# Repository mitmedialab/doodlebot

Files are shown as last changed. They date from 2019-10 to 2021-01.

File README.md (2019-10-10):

# The Minimal theme

 

*Minimal is a Jekyll theme for GitHub Pages. You can [preview the theme to see what it looks like](http://pages-themes.github.io/minimal), or even [use it today](#usage).*

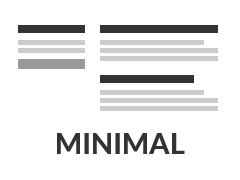
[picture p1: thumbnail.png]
Thumbnail of minimal


## Usage

To use the Minimal theme:

1. Add the following to your site's `_config.yml`:

    ```yml
    theme: jekyll-theme-minimal
    ```

2. Optionally, if you'd like to preview your site on your computer, add the following to your site's `Gemfile`:

    ```ruby
    gem "github-pages", group: :jekyll_plugins
    ```

## Customizing

### Configuration variables

Minimal will respect the following variables, if set in your site's `_config.yml`:

```yml
title: [The title of your site]
description: [A short description of your site's purpose]
```

Additionally, you may choose to set the following optional variables:

```yml
logo: [Location of the logo]
show_downloads: ["true" or "false" to indicate whether to provide a download URL]
google_analytics: [Your Google Analytics tracking ID]
```

### Stylesheet

If you'd like to add your own custom styles:

1. Create a file called `/assets/css/style.scss` in your site
2. Add the following content to the top of the file, exactly as shown:
    ```scss
    ---
    ---

    @import "{{ site.theme }}";
    ```
3. Add any custom CSS (or Sass, including imports) you'd like immediately after the `@import` line

### Layouts

If you'd like to change the theme's HTML layout:

1. [Copy the original template](https://github.com/pages-themes/minimal/blob/master/_layouts/default.html) from the theme's repository<br />(*Pro-tip: click "raw" to make copying easier*)
2. Create a file called `/_layouts/default.html` in your site
3. Paste the default layout content copied in the first step
4. Customize the layout as you'd like

## Roadmap

See the [open issues](https://github.com/pages-themes/minimal/issues) for a list of proposed features (and known issues).

## Project philosophy

The Minimal theme is intended to make it quick and easy for GitHub Pages users to create their first (or 100th) website. The theme should meet the vast majority of users' needs out of the box, erring on the side of simplicity rather than flexibility, and provide users the opportunity to opt-in to additional complexity if they have specific needs or wish to further customize their experience (such as adding custom CSS or modifying the default layout). It should also look great, but that goes without saying.

## Contributing

Interested in contributing to Minimal? We'd love your help. Minimal is an open source project, built one contribution at a time by users like you. See [the CONTRIBUTING file](docs/CONTRIBUTING.md) for instructions on how to contribute.

### Previewing the theme locally

If you'd like to preview the theme locally (for example, in the process of proposing a change):

1. Clone down the theme's repository (`git clone https://github.com/pages-themes/minimal`)
2. `cd` into the theme's directory
3. Run `script/bootstrap` to install the necessary dependencies
4. Run `bundle exec jekyll serve` to start the preview server
5. Visit [`localhost:4000`](http://localhost:4000) in your browser to preview the theme

### Running tests

The theme contains a minimal test suite, to ensure a site with the theme would build successfully. To run the tests, simply run `script/cibuild`. You'll need to run `script/bootstrap` one before the test script will work.

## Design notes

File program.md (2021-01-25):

## Program Your DoodleBot!

Connect the Doodle Bot to the computer using a USB cord. 

Download Arduino IDE from [https://www.arduino.cc/en/main/software](https://www.arduino.cc/en/main/software)  or use the online Arduino tool at [https://create.arduino.cc](https://create.arduino.cc) 

First upload the following code to the Doodle bot to check for calibration of the bot. This programs the robot to draw 4 rectangles on top of each other. If your robot does not draw the rectangles on top of each other, then the wheels are not calibrated accurately. 

Note that you need to select your Arduino type in **Tools > Board > Arduino Nano** (or whichever Arduino you are using) 

Note that you must also select the appropriate port in **Tools > Port > USB-XX** (port name shows up when you connect your bot to the computer using USB)

```
#include <Servo.h>

// setup servo
int servoPin = 8;
int PEN_DOWN = 20; // angle of servo when pen is down
int PEN_UP = 80;   // angle of servo when pen is up
Servo penServo;

float wheel_dia=63; //    # mm (increase = spiral out)
float wheel_base=109; //    # mm (increase = spiral in, ccw) 
int steps_rev=128; //        # 512 for 64x gearbox, 128 for 16x gearbox
int delay_time=6; //         # time between steps in ms

// Stepper sequence org->pink->blue->yel
int L_stepper_pins[] = {12, 10, 9, 11};
int R_stepper_pins[] = {4, 6, 7, 5};

int fwd_mask[][4] =  {1, 0, 1, 0}, {0, 1, 1, 0}, {0, 1, 0, 1}, {1, 0, 0, 1};

int rev_mask[][4] =  {1, 0, 0, 1},{0, 1, 0, 1},{0, 1, 1, 0},{1, 0, 1, 0};

void setup() {
  randomSeed(analogRead(1)); 
  Serial.begin(9600);
  for(int pin=0; pin<4; pin++){
    pinMode(L_stepper_pins[pin], OUTPUT);
    digitalWrite(L_stepper_pins[pin], LOW);
    pinMode(R_stepper_pins[pin], OUTPUT);
    digitalWrite(R_stepper_pins[pin], LOW);
  }
  penServo.attach(servoPin);
  Serial.println("setup");
  
  penup();
  
  delay(1000);
}

void loop(){ // draw a calibration box 4 times
  pendown();
  for(int x=0; x<12; x++){
    forward(100);
    left(90);
  }
  penup();
  done();      // releases stepper motor
  while(1);    // wait for reset
}

// ----- HELPER FUNCTIONS -----------
int step(float distance){
  int steps = distance * steps_rev / (wheel_dia * 3.1412); //24.61
  /*
  Serial.print(distance);
  Serial.print(" ");
  Serial.print(steps_rev);
  Serial.print(" ");  
  Serial.print(wheel_dia);
  Serial.print(" ");  
  Serial.println(steps);
  delay(1000);*/
  return steps;  
}

void forward(float distance){
  int steps = step(distance);
  Serial.println(steps);
  for(int step=0; step<steps; step++){
    for(int mask=0; mask<4; mask++){
      for(int pin=0; pin<4; pin++){
        digitalWrite(L_stepper_pins[pin], rev_mask[mask][pin]);
        digitalWrite(R_stepper_pins[pin], fwd_mask[mask][pin]);
      }
      delay(delay_time);
    } 
  }
}

void backward(float distance){
  int steps = step(distance);
  for(int step=0; step<steps; step++){
    for(int mask=0; mask<4; mask++){
      for(int pin=0; pin<4; pin++){
        digitalWrite(L_stepper_pins[pin], fwd_mask[mask][pin]);
        digitalWrite(R_stepper_pins[pin], rev_mask[mask][pin]);
      }
      delay(delay_time);
    } 
  }
}

void right(float degrees){
  float rotation = degrees / 360.0;
  float distance = wheel_base * 3.1412 * rotation;
  int steps = step(distance);
  for(int step=0; step<steps; step++){
    for(int mask=0; mask<4; mask++){
      for(int pin=0; pin<4; pin++){
        digitalWrite(R_stepper_pins[pin], rev_mask[mask][pin]);
        digitalWrite(L_stepper_pins[pin], rev_mask[mask][pin]);
      }
      delay(delay_time);
    } 
  }   
}

void left(float degrees){
  float rotation = degrees / 360.0;
  float distance = wheel_base * 3.1412 * rotation;
  int steps = step(distance);
  for(int step=0; step<steps; step++){
    for(int mask=0; mask<4; mask++){
      for(int pin=0; pin<4; pin++){
        digitalWrite(R_stepper_pins[pin], fwd_mask[mask][pin]);
        digitalWrite(L_stepper_pins[pin], fwd_mask[mask][pin]);
      }
      delay(delay_time);
    } 
  }   
}

void done(){ // unlock stepper to save battery
  for(int mask=0; mask<4; mask++){
    for(int pin=0; pin<4; pin++){
      digitalWrite(R_stepper_pins[pin], LOW);
      digitalWrite(L_stepper_pins[pin], LOW);
    }
    delay(delay_time);
  }
}

void penup(){
  delay(250);
  Serial.println("PEN_UP()");
  penServo.write(PEN_UP);
  delay(250);
}

void pendown(){
  delay(250);  
  Serial.println("PEN_DOWN()");
  penServo.write(PEN_DOWN);
  delay(250);
}

```

Calibration functions 

```
void loop(){ // draw a calibration box 4 times
  pendown();
  for(int x=0; x<12; x++){
    forward(100);
    left(90);
  }
  penup();
  done();      // releases stepper motor
  while(1);    // wait for reset
}
```

```
void loop(){ // draw a calibration Octagon 2 times
  pendown();
  for(int x=0; x<16; x++){
    forward(100);
    left(45);
  }
  penup();
  done();      // releases stepper motor
  while(1);    // wait for reset
}
```

```
void loop(){ // draw 2 concentric circles - try out resolutions
  pendown();
  for(int x=0; x<180; x++){
    forward(2);
    left(2);
  }
  penup();

  right(90);
  forward(100);
  left(90);

  pendown();
  for(int x=0; x<180; x++){
    forward(2);
    left(2);
  }
  penup();

  done();      // releases stepper motor
  while(1);    // wait for reset
}
```

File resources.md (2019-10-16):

# Resources

**STL and CAD files for 3D printing**: https://github.com/mitmedialab/doodlebot/blob/master/parts

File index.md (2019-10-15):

---
layout: default
---

Doodle Bot is a robot-based Creative AI learning platform for High School students. It consists of an introduction to robotics, hardware, arduino programming and machine learning.

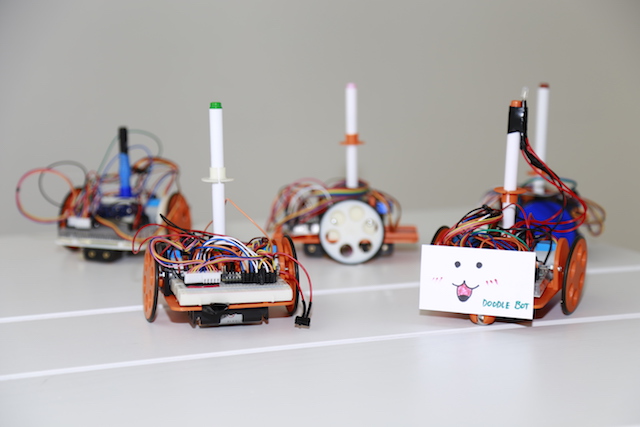
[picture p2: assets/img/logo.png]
MainImage


Doodle Bot has three main modules : 

* **Construction** : Students learn how to print and construct the robot. Students learn physical fabrication, hardware skills, electronics and circuit design. 
* **Programming** : Students learn how to program the robot to draw different shapes. Students gain Arduino programming skills. Students also learn converting stroke paths to Arduino paths.
* **Training** : Students learn the basics of Machine Learning (Classification, Generative Networks). Students train their robot in ways specific to their project. 

In addition, you can also refer to our [projects gallery](./projects.html) for previous projects, and [resources](./resources.html) to download model files and source code.  

This project is developed and maintained by MIT. Note that the Doodle robot and its training module has been used for robotics and STEM workshop for over 30 high school students in the US and Mexico. 

For any questions and suggestions, please contact : 

* Safinah Ali : safinah@mit.edu
* Nisha Devasia : ndevasia@mit.edu

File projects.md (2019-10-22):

# Projects

Here are some DoodleBot projects that were created this summer!

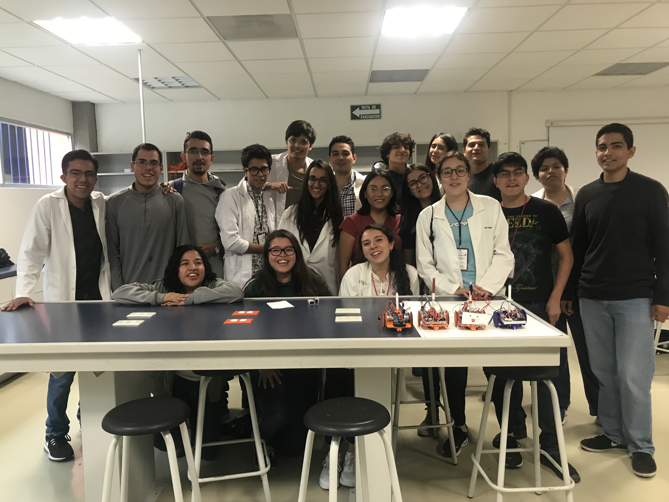
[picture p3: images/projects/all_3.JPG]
The entire team!

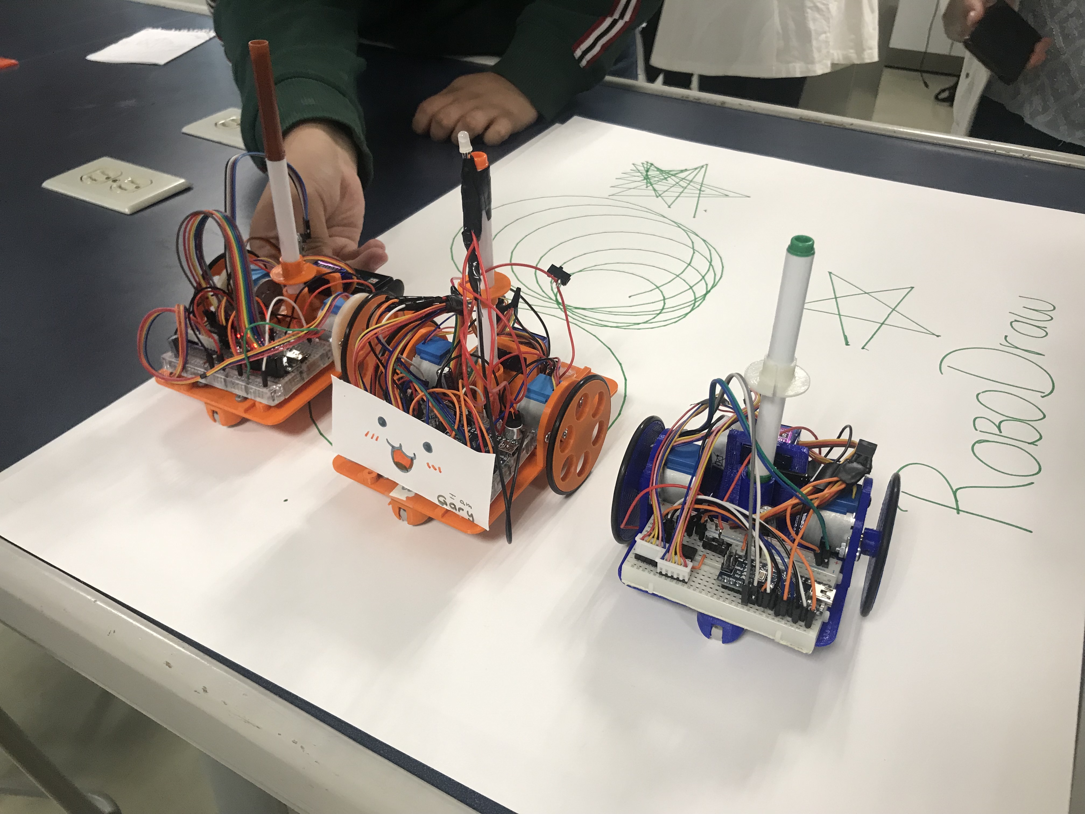
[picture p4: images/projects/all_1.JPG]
The doodlebots

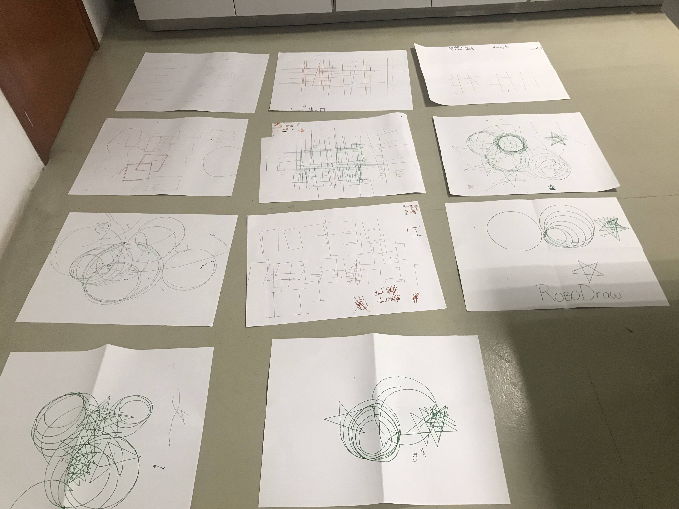
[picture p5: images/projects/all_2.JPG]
Doodlebot drawings


## Team 1

Here is an individual project, [project name], created by [team members]. 

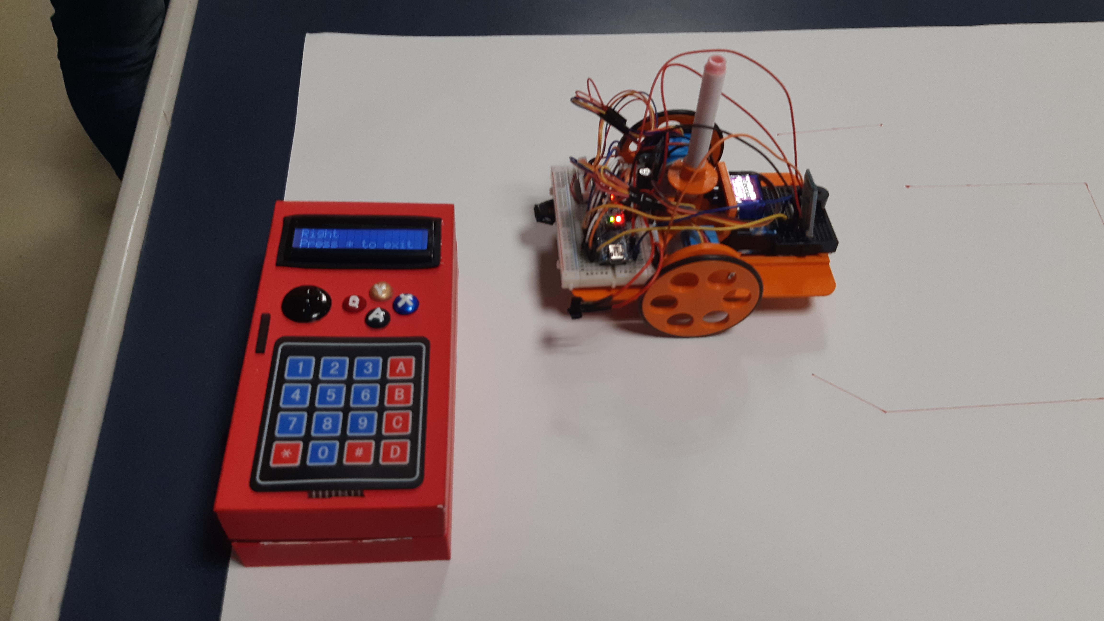
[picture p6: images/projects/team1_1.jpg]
project

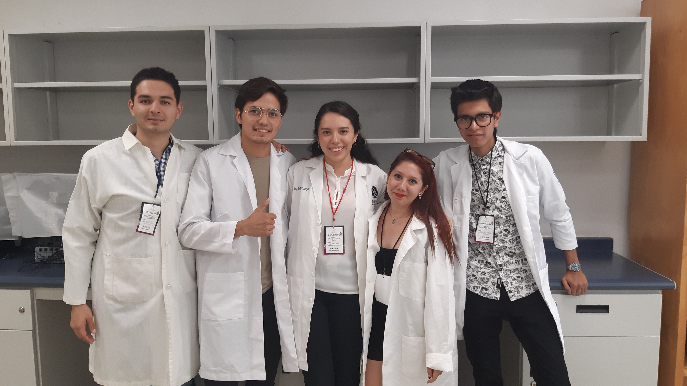
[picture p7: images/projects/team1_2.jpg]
project


## Team 2

Here is an individual project, [project name], created by [team members]. 

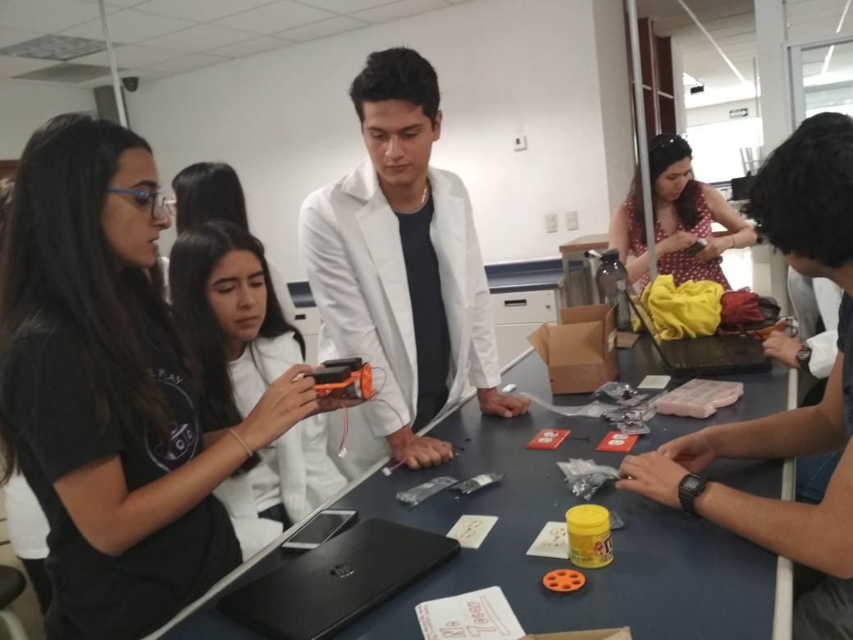
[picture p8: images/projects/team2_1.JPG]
project


## Team 3

Here is an individual project, [project name], created by [team members]. 

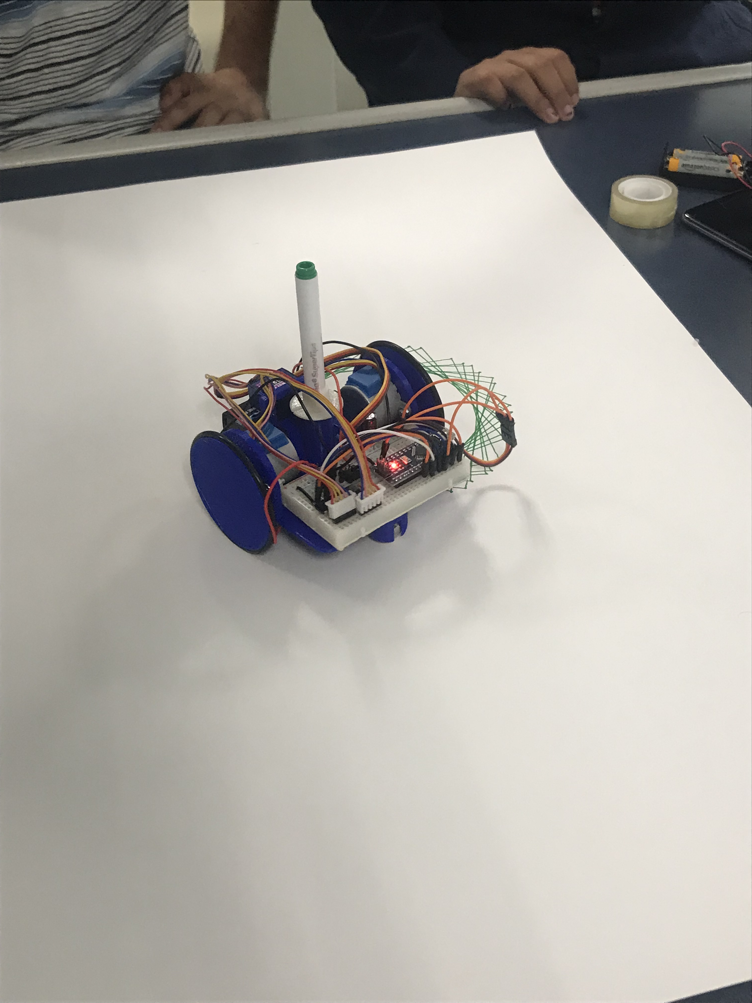
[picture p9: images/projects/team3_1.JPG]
project


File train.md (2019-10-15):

# Train Your DoodleBot!

## Sound classification

**Main steps:**

1. Set up a server with the boilerplace that uses ML5
2. Use a pre-trained model speech-commands to recognize speech
3. Design a web interface that recognized the speech word and prints it to a file
4. Use this file to load the current speech and send it to Arduino 

**Step 1: Set up a server with the boilerplate that uses ML5**

1. Download the boilerplate here : https://drive.google.com/open?id=14w6u65YhrZ5H0LI_JHK-Zqxa3Mltz3X1
2. In the folder above, you will find two files : index.html and sketch.js. Your HTML code (interface) will go in index.html file, and your Javascript code will go in the sketch.js file. 
3. Let’s examine the files : 
  a. index.html 

  Verify that your code in **index.html** looks like this: 

  This code contains html tags <head> and <body>. In the ```<head>```, we load all the p5.js libraries which are responsible for the look and feel of the webpage and in the ```<body>```, we load the sketch.js file, while is responsible for the logic of the webpage. 

```html
<!DOCTYPE html>
<html lang="en">
  <head>
    <title>Getting Started with ml5.js</title>
    <!-- p5 -->
    <script src="https://cdnjs.cloudflare.com/ajax/libs/p5.js/0.8.0/p5.min.js"></script>
    <script src="https://cdnjs.cloudflare.com/ajax/libs/p5.js/0.8.0/addons/p5.dom.min.js"></script>
    <script src="https://cdnjs.cloudflare.com/ajax/libs/p5.js/0.8.0/addons/p5.sound.min.js"></script>
    <!-- ml5 -->
    <script src="https://unpkg.com/ml5@0.3.0/dist/ml5.min.js"></script>
  </head>

  <body>
    <script src="sketch.js"></script>
  </body>
</html>
```

  b. sketch.js

This is the base sketch file. All p5.js files have a setup() function, where you set up your space, and a draw() which updates constantly to run stuff. To learn more, go to: https://p5js.org

```javascript
console.log('ml5 version:', ml5.version);

function setup(){
    createCanvas(400, 400);
}

function draw(){
    background(200);
    
}
```

In this **sketch.js** file, we simply make a canvas and we print the ml5 version to our console in the browser. We will first test if this works.
	
  c. Run the server. 

In order to test if this is working, we will run a local server. 

Go to your terminal, and navigate to the directory: 

  * First navigate to home directory in the terminal: 
  ```cd```
  * Then navigate to the project directory (this will depend on where your boilerplate folder is):
  ```cd Documents/biolerplate-sound```

Your folder might be in downloads instead of documents for example, if this is the case, replace the ```cd Documents/``` part with ```cd Downloads/```.

  * In this folder, run the following command in your terminal to start a local server : 
  ```python -m SimpleHTTPServer 8000```

  * If you get an error here, check what python version you have by using which python in your terminal. It should give you a result like : ```/Library/Frameworks/Python.framework/Versions/2.7/bin/python```.

  * This also works:
  ```(//anaconda3/bin/python)```
  If this is the case put this in instead:
   ```python3 -m http.server```

  * If it leads to no result, it means you need to install python. 

  * In order to test if the server is running, go to: http://localhost:8000 in your browser and you should see this: 

If you right click and go to ```inspect element >``` and then select the ‘console’ tab, you can see the browser’s console. In the console, you should see: ```0.3.0``` to verify that your server is working correctly. 

Now stop your server in the terminal. If you Control+C in your terminal, the server should stop. 

## Step 2: Use a pre-trained model SoundClassifier to recognize speech words : 

The model we will be using is called speech-commands recognizer model. The ml5.soundClassifier() allows you to classify audio. With the right pre-trained models, you can detect whether a certain noise was made (e.g. a clapping sound or a whistle) or a certain word was said (e.g. Up, Down, Yes, No). At this moment, with the ml5.soundClassifier(), you can use the "SpeechCommands18w" which can recognize "the ten digits from "zero" to "nine", "up", "down", "left", "right", "go", "stop", "yes", "no", as well as the additional categories of "unknown word" and "background noise"."

To read more about this mode, go to : https://github.com/tensorflow/tfjs-models/tree/master/speech-commands

For our application, we will use numbers, directions, “go”, and “stop” to make the doodle bot draw things. Ensure that your Arduino file has functions for all of these (zero" to "nine", "up", "down", "left", "right", "go", "stop")

  1. Open the index.html file. In the <head> tag, let’s first make the title of the page relevant to sound classification. 

  ```html
  <title>Sound classification using SpeechCommands18w and p5.js</title>
```

  In the body tag, we will write some info to display what the model is actually doing.
  
```html
<body>
  <h1>Sound classification using SpeechCommands18w and p5.js</h1>
  <p>Try to speak the following commands to your microphone: 'zero', 'one', 'two', 'three', 'four', 'five', 'six', 'seven', 'eight', 'nine', 'up', 'down', 'left', 'right', 'go', 'stop', 'yes', and 'no', in addition to 'background_noise' and 'unknown'</p>
  <script src="sketch.js"></script>
</body>
```

  2. Open the **sketch.js** file. Let’s first get rid of the createCanvas from the biolerplate, since we don’t need that. In addition to the setup() and sketch() function, we will add a preload() function before setup(). The preload() function loads the model in advance, in effect saving us time to load the model (when it is added in setup()), even before the interface is loaded. We do this since it quickens the process of loading the model, which is typically time consuming.

```javascript
function preload() {
  // Load SpeechCommands18w sound classifier model
  classifier = ml5.soundClassifier('SpeechCommands18w', options);
}
```

  3. We will now declare some variables in the beginning of **sketch.js**.

```javascript
// Initialize a sound classifier method with SpeechCommands18w model.
let classifier;
// Options for the SpeechCommands18w model, the default probabilityThreshold is 0
const options = { probabilityThreshold: 0.7 };
// Two variable to hold the label and confidence of the result
let label;
let confidence;
```

  4. setup() function:

```javascript
function setup() {
  noCanvas();
  // Create 'label' and 'confidence' div to hold results
  label = createDiv('Label: ...');
  confidence = createDiv('Confidence: ...');
  // Classify the sound from microphone in real time
  classifier.classify(gotResult);
}

  5. gotResult() function:
```javascript
// A function to run when we get any errors and the results
function gotResult(error, results) {
  // Display error in the console
  if (error) {
    console.error(error);
  }
  // The results are in an array ordered by confidence.
  console.log(results);
  // Show the first label and confidence
  label.html('Label: ' + results[0].label);
  confidence.html('Confidence: ' + nf(results[0].confidence, 0, 2)); // Round the confidence to 0.01
}
```

  6. Finally, your **sketch.js** file should look this this: 

```javascript
// Initialize a sound classifier method with SpeechCommands18w model. A callback needs to be passed.
let classifier;
// Options for the SpeechCommands18w model, the default probabilityThreshold is 0
const options = { probabilityThreshold: 0.7 };
// Two variable to hold the label and confidence of the result
let label;
let confidence;

function preload() {
  // Load SpeechCommands18w sound classifier model
  classifier = ml5.soundClassifier('SpeechCommands18w', options);
}

function setup() {
  noCanvas();
  // Create 'label' and 'confidence' div to hold results
  label = createDiv('Label: ...');
  confidence = createDiv('Confidence: ...');
  // Classify the sound from microphone in real time
  classifier.classify(gotResult);
}

// A function to run when we get any errors and the results
function gotResult(error, results) {
  // Display error in the console
  if (error) {
    console.error(error);
  }
  // The results are in an array ordered by confidence.
  console.log(results);
  // Show the first label and confidence
  label.html('Label: ' + results[0].label);
  confidence.html('Confidence: ' + nf(results[0].confidence, 0, 2)); // Round the confidence to 0.01
}
```

Now run your server again (Step 3.c.) and load the localhost in your browser. 

  7. Now write the result to a file in your arduino folder by using the write(data) function of p5.js. Read that file using Arduino IDE to tell the robot what to draw. 

  For reference: 
  * P5.js side (in your sketch.js file) : https://p5js.org/reference/#/p5.PrintWriter/write
  * Arduino side (in your .ino file) https://www.arduino.cc/en/Reference/FileRead

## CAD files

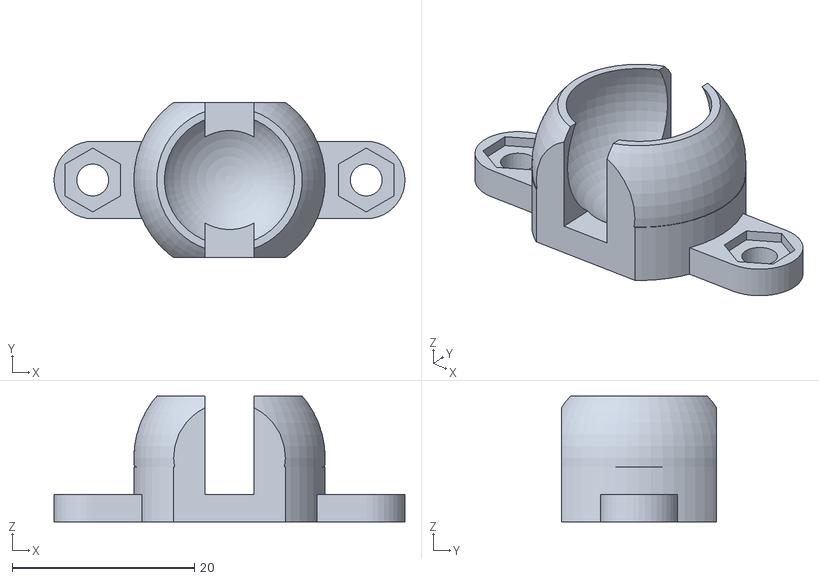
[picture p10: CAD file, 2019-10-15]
parts/STL files/Caster2.stl
38.5 x 17.0 x 13.8

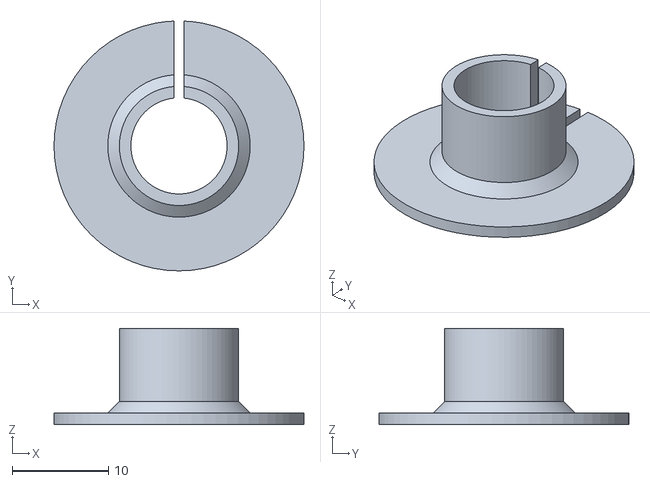
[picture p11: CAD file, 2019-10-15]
parts/STL files/Pen_Collar2.stl
26.0 x 26.0 x 10.0

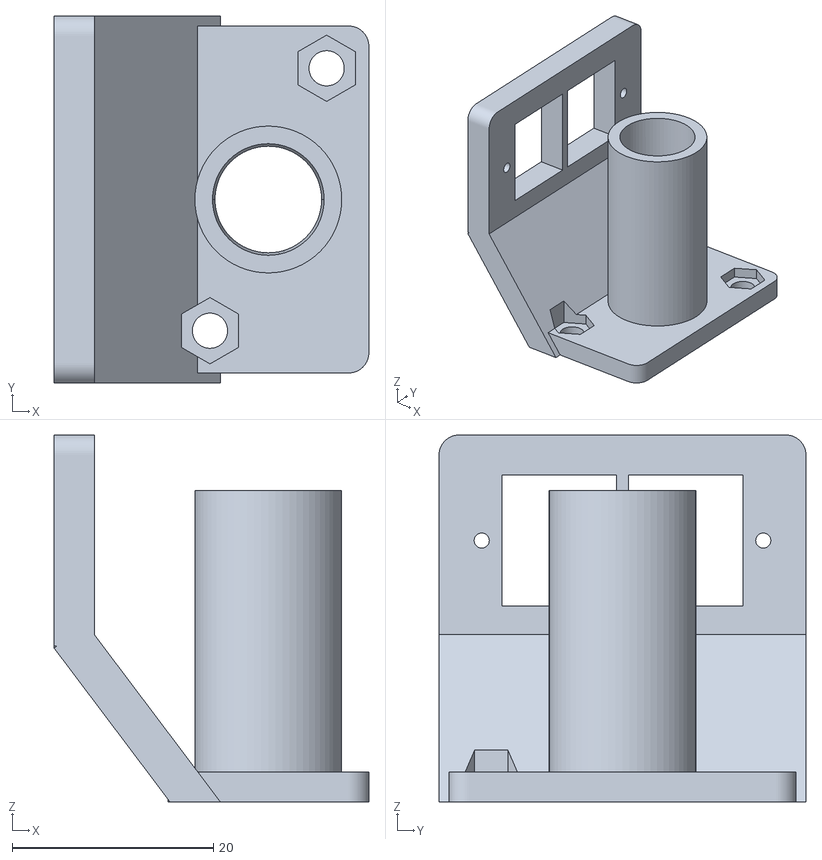
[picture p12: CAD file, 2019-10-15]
parts/STL files/Pen_Holder2.stl
31.3 x 36.5 x 36.5

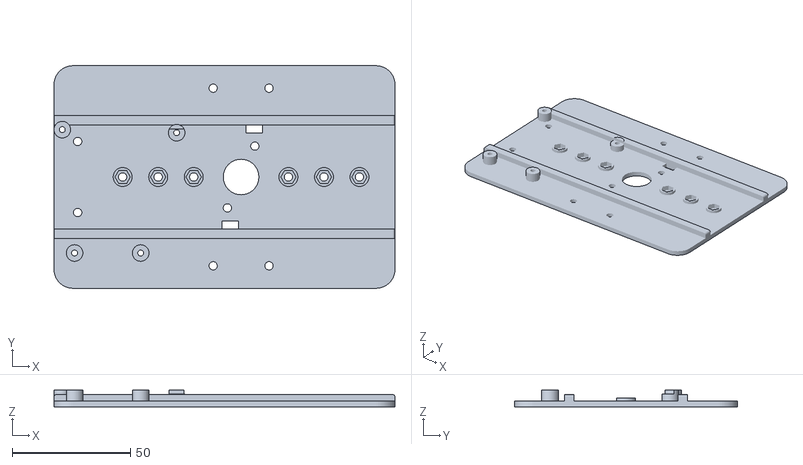
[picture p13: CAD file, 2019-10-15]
parts/STL files/Chassis_Arduino2.stl
144.0 x 94.0 x 7.00

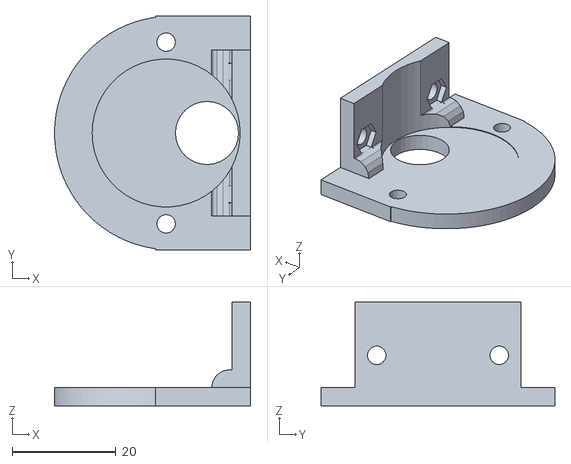
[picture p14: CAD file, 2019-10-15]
parts/STL files/Stepper_Bracket2.stl
37.8 x 45.0 x 20.0

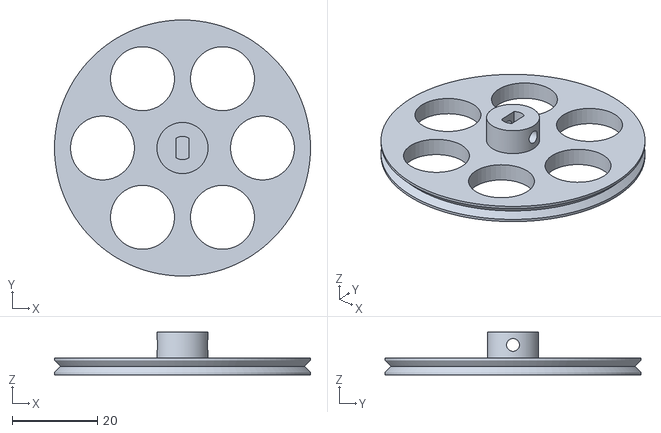
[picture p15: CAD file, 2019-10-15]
parts/STL files/Wheel_60_spokes.stl
60.0 x 60.0 x 10.0

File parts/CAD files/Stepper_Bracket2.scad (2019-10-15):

// Original :http://www.thingiverse.com/thing:423357
// Bracket for  28BYJ-48 stepper motor
// 28BYJ-48 model from RGriffoGoes www.thingiverse.com/thing:204734
// added details by J.Beale 21 July 2014
// Bracket by J.Beale 9 Aug 2014

slop = 0.25;  // printer tolerance

// =========================================================
// stepper motor body model

MBH = 18.8;   // motor body height
MBD = 28.25+slop;  // motor body OD
SBD = 9.1+slop;    // shaft boss OD
SBH = 1.45;   // shaft boss height above motor body
SBO = 7.875;  // offset of shaft/boss center from motor center
//SHD = 4.93+slop*2;   // motor shaft OD+ countersink for boss
SHD = 11.9+slop;   // motor shaft OD (larger clearance hole)
SHDF = 3.0;   // motor shaft diameter, across flats
SHHF = 6.0;   // motor shaft flats height, or depth in from end
SHHF = 0.0;   // assume round shaft for purposes of bracket
SHH = 9.75;   // height of shaft above motor body 

MBFH = 0.7;   // height of body edge flange protruding above surface
MBFW = 1.0+slop;   // width of edge flange
MBFNW = 8;    // width of notch in edge flange
MBFNW2 = 17.8;  // width of edge flange notch above wiring box

MHCC = 35.0;  // mounting hole center-to-center was 35
MTH  = 0.8;   // mounting tab thickness
MTW  = 0.0;   // mounting tab width
// MTHID = 4.0;  // mounting tab hole inner diameter
MTHID = 3.0;  // mounting tab hole inner diameter
WBH  = 16.7;  // plastic wiring box height
WBW  = 14.6+slop;  // plastic wiring box width
WBD  = 31.3+slop;  // body diameter to outer surface of wiring box

WRD = 1.0;     // diameter of electrical wires
WRL = 30;      // length of electrical wires
WRO = 2.2;		// offset of wires below top motor surface
// =========================================================
// right-angle bracket for motor

MSOD = 6.0 + slop;  // M3 mounting screw head diameter // WAS 5.9
MSTH = 1.5;  // M3 screw head thickness (for countersink)
//MSTH = 0; // set to zero for no screwhead countersink
MSSD = 3.3 + slop;  // M3 screw diameter clearance hole // WAS 3.1
Bthick = 3.5;  // thickness of bracket
Bdia = (MHCC+10);  // diameter of bracket face
M3nutDia = 6.5;

// =========================================================
fn = 80;
eps = 0.05;   // small number to avoid coincident faces

motorOffset = 3;


module StepMotor28BYJ()
{
  difference(){
    union(){
	   color("gray") translate([0,0,-(MBH+MBFH)/2])
	  difference() {  // flange at top rim
        // cylinder(h = MBFH+eps, r = MBD/2, center = true, $fn = 50);
         //cylinder(h = MBFH+2*eps, r = (MBD-MBFW)/2, center = true, $fn = 32);
			//cube([MBFNW,MHCC,MBFH*2],center=true); // notches in rim
			//cube([MBD+2*MBFW,SBD,MBFH*2],center=true);
		   //translate([-MBD/2,0,0]) cube([MBD,MBFNW2,MBFH*2],center=true);
        }
		color("gray") // motor body
			cylinder(h = MBH, r = MBD/2, center = true, $fn = 50);
		color("gray") translate([SBO,0,-SBH])	// shaft boss
			cylinder(h = MBH, r = SBD/2, center = true, $fn = 32);

		translate([SBO,0,-SHH])	// motor shaft
        difference() {
			color("gold") cylinder(h = MBH, r = SHD/2, center = true, $fn = 32);
				// shaft flats
		   color("red") translate([(SHD+SHDF)/2,0,-(eps+MBH-SHHF)/2]) 
				cube([SHD,SHD,SHHF], center = true);
		   color("red") translate([-(SHD+SHDF)/2,0,-(eps+MBH-SHHF)/2]) 
				cube([SHD,SHD,SHHF], center = true);
        }


		//color("Silver") translate([0,0,-(MBH-MTH-eps)/2]) // mounting tab 
		//	cube([MTW,MHCC,MTH], center = true);				
		//color("Silver") translate([0,MHCC/2,-(MBH-MTH)/2]) // mt.tab rounded end
		//	cylinder(h = MTH, r = MTW/2, center = true, $fn = 32);
		//color("Silver") translate([0,-MHCC/2,-(MBH-MTH)/2]) // mt.tab rounded end
		//	cylinder(h = MTH, r = MTW/2, center = true, $fn = 32);


		//color("blue") translate([-(WBD-MBD),0,eps-(MBH-WBH)/2]) // plastic wire box
		//	cube([MBD,WBW,WBH], center = true);
	    //color("blue") translate([-2,0,0])	
		//	cube([24.5,16,15], center = true);
		}

				// mounting holes in tabs on side
		color("red") translate([0,MHCC/2,-MBH/2])	
				cylinder(h = 2, r = MTHID/2, center = true, $fn = 32);
		color("red") translate([0,-MHCC/2,-MBH/2])	
				cylinder(h = 2, r = MTHID/2, center = true, $fn = 32);
		}
}



module MOT() {
 translate([motorOffset,0,-MBH/2 ]) 
 rotate([180,0,0]) StepMotor28BYJ();  // motor body (without wires)
}


module bracket() {
difference() {
 union() {
  translate([motorOffset,0,-Bthick/2]) cylinder(h=Bthick, r=Bdia/2, $fn=fn);  // round face
     
  echo(Bdia);
  translate([-eps + MBD/2 + 0.5,-32/2,-20+Bthick/2]) 
  		cube([5.5+eps,32,20]); // flange
     
     
  translate([-0,-Bdia/2,-Bthick/2]) 
	cube([Bdia,Bdia,Bthick]); // square edge joining round face to flange
  translate([MBD/2,32/2,-Bthick/2]) rotate([90,0,0]) 
  	cylinder(r=Bthick,h=32,$fn=16); // round fillet at flange
 }
 
 union() {
   translate([4+MBD/2,-MBD,-MBD]) cube([MBD*2,MBD*2,MBD*2]);
   translate([motorOffset - 1,MHCC/2,-10])	// motor mounting bolt
   			cylinder(h = 30, r = MSSD/2, center = true, $fn = 32);
   translate([motorOffset - 1,-MHCC/2,-10])	// motor mounting bole
				cylinder(h = 30, r = MSSD/2, center = true, $fn = 32);



   translate([1.0,11.8,-8]) rotate([0,90,0]) 	// flange mounting bolt
     rotate([0, 0, 30])
				cylinder(h = 30, d = M3nutDia, center = true, $fn = 6);   
   translate([10,11.8,-8]) rotate([0,90,0]) 	// flange mounting bolt
				//cylinder(h = 30, r = MSOD/2, center = true, $fn = 6);                
				cylinder(h = 30, r = MSSD/2, center = true, $fn = 32);
     
   translate([1.0,-11.8,-8]) rotate([0,90,0]) 	// flange mounting bolt
     rotate([0, 0, 30])     
				cylinder(h = 30, d = M3nutDia, center = true, $fn = 6);        
   translate([10,-11.8,-8]) rotate([0,90,0]) 	// flange mounting bolt
				cylinder(h = 30, r = MSSD/2, center = true, $fn = 32);

   color("white") translate([motorOffset - 1, MHCC/2,((Bthick/2) - MSTH + eps)]) 
	 cylinder(r=MSOD/2, h=MSTH, $fn=25); // motor screw countersink
   color("white") translate([motorOffset - 1,-MHCC/2,((Bthick/2) - MSTH + eps)])  
	 cylinder(r=MSOD/2, h=MSTH, $fn=25); // motor screw countersink

   translate([-1,0,-1.6]) MOT(); // body of motor
   //translate([0,0,-10]) cube([50,50,50]); // DEBUG cutaway view
 }
}
} // end module()

rotate([180,0,0]) bracket();  // show the motor bracket

//bracket();
//StepMotor28BYJ();

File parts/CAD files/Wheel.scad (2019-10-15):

// Original script by Mark Benson
// http://www.thingverse.com/thing:122070
// 23/07/2013

// Wheel for maze mouse
// Shaft fitting for 28BYJ-48 geared stepper

// Modified by 648.ken@gmail.com Jun 2015
// Lengthened hub
// increased shaft cutout
// Included M3 set screw hole (might need to be tapped)
// Added parameters for customizer

// Creative commons non commercial


// http://www.thingiverse.com/thing:16193/
use <write/Write.scad>


/* [Global] */
features = "spokes"; // [spokes, text, plain, hub-only]

/* [Wheel] */
// Diameter of wheel in mm.
wheel_diameter = 60;

// Increase shaft cutout size in mm if your printer is not calibrated.
fudge_factor = 0;

/* [Text] */

// You will have to flip it around to see it. 
text = "ChickTech  Rules!";

// Font selection
font = "orbitron.dxf"; // [orbitron.dxf, BlackRose.dxf, knewave.dxf, braille.dxf, Letters.dxf]

// 8mm goes all the way through, but may cause trouble with letters like "B".
letter_depth = 1; // [0:8]

// Letter spacing
letter_spacing = 1.2; 

// Letter height in mm.
letter_height = 8;


difference(){
	union()	{
		//rim
        if (features != "hub-only"){
            cylinder(r=wheel_diameter / 2, h=4, $fn=100);
        }

		//boss
		cylinder(r=12 / 2, h=10, $fn=100);
	}


	union()	{
		//shaft cutout (shaft with flat)
		translate([0, 0, 0.6])
		intersection(){
			cylinder(r=5.5 / 2 + fudge_factor, h=12, $fn=40); // was 5
			translate([0, 0, 4]) cube([3.0 + fudge_factor, 12, 12], 
                                       center=true); // was 2.5
		}

		// set screw for M3
		translate([0, 0, 7])		
		rotate([90, 0, 90])
		cylinder(r=1.5, h=60, center=true, $fn=40); // was 1

		//rim groove cutout
		translate([0, 0, 2])
		rotate_extrude(convexity=10, $fn=100)
		translate([wheel_diameter / 2, 0, 10])
		rotate([0,0,45])
		square([2,2],center=true);

        // add text to face
        if (features == "text"){
            if(letter_depth > 0){
                rotate(180, [1, 0, 0]){
                    writecircle(text, [0, 0, 0], 
                                wheel_diameter / 2 - letter_height, 
                                font=font, space=letter_spacing, 
                                t=letter_depth, h=letter_height);
                }
            }
        }
        // add spokes (circular cut-outs)        
        if (features == "spokes"){
            for(i = [0:5]){
                rotate(i * 360 / 6, [0, 0, 1])
                translate([wheel_diameter / 3.2, 0, -1])
                cylinder(r=wheel_diameter / 8, h=8, $fn=40);
            }
        }
	}
}

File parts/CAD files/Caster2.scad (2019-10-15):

// Original: http://www.thingiverse.com/thing:8959/
// Marble Caster by HipsterLogic

// Modified by 648.ken@gmail.com
// MakersBox.blogspot.com

// Added tapper the top lip to keep it from snagging on things.
// Added recess for screw heads if baseThickness > 3mm
// Added pedistal base so you can adjust platform hieght.


deckHeight = 21;    // from chassis bottom to ground, (must be at lease ballDiameter)
ballDiameter = 16;    // 7/16" ball bearing = 12.25mm, WAS 16.5  16mm = 5/8" ball bearing
ballTolerance = 0.4;  // play between ball and surface
wallThickness = 2.5;
gapWidth = ballDiameter / 3;
baseThickness = 4; // WAS 3


//baseHeight = ballDiameter + wallThickness * 2;
pedistalWidth = ballDiameter + wallThickness * 2;

baseWidth = 30; // distance between mounting holes

M3holeDia = 3.5;
M3nutDia = 6.5;


echo(deckHeight);
baseHeight = deckHeight - ballDiameter / 2;
echo(baseHeight);

module mainShape(){

    // mounting cross-piece
	translate([-baseWidth/2, -wallThickness - M3holeDia / 2, 0]) 
        cube([baseWidth, wallThickness * 2 + M3holeDia, baseThickness]);
	
	// bolt ends
	translate([baseWidth / 2, 0, 0]) 
        cylinder(baseThickness, M3holeDia / 2 + wallThickness, M3holeDia / 2 + wallThickness, $fn=40);
	translate([-baseWidth / 2, 0, 0]) 
        cylinder(baseThickness, M3holeDia / 2 + wallThickness, M3holeDia / 2 + wallThickness, $fn=40);

	// main cylindrical body
	translate([0, 0, 0])
        cylinder(baseHeight - 3, pedistalWidth / 2, pedistalWidth / 2, $fn=50);

	difference(){
        // tapper shere at top
		translate([0, 0, baseHeight - 2])
            sphere(pedistalWidth / 2, $fn=50);
                
        // shave the top flat
		translate([0, 0, baseHeight + ballDiameter / 2 - ballDiameter / 5])
            cylinder(25, 25, 25, $fn=50);
        
		// shave the bottom	flat	
		translate([0, 0, -12])
            cylinder(12, 25, 25, $fn=50);
  
	};
}

module cutout(){
    
    // ball hole
	translate([0, 0, baseHeight + ballTolerance]) 
        sphere(ballDiameter / 2 + ballTolerance, $fn=50);
	
    // slot to remove ball
    slotOffset = ballDiameter / 2.5;  // distance below baseHeight to cut slot
    if (baseHeight - slotOffset > baseThickness){
        translate([-gapWidth / 2, -baseWidth / 2, 
                   baseHeight - slotOffset]) 
            cube([gapWidth, baseWidth, ballDiameter]);
        
        }
    else{ // don't cut into base
        translate([-gapWidth / 2, -baseWidth / 2, 
                   baseThickness]) 
            cube([gapWidth, baseWidth, ballDiameter]);        
    }
    
    //trim sides
    translate([-25, ballDiameter / 2 + 0.5, 0]) 
            cube([50, ballDiameter, 50]);      

    translate([-25, -ballDiameter - 0.5, 0]) 
            cube([50, ballDiameter / 2, 50]);    

    if ((baseHeight - ballDiameter / 2) > baseThickness){
         // ball void to save material
        translate([0, 0, baseHeight - ballDiameter - 1]) 
            sphere(ballDiameter / 2, $fn=50);
    }

}

module mountingHoles(){
    // left m3 hole
	translate([baseWidth / 2, 0, 0])
	cylinder(baseThickness + 2, M3holeDia / 2, M3holeDia / 2, $fn=30);

    // countersink
	translate([baseWidth / 2, 0, 2]) 
    rotate([0, 0, 30])
	cylinder(baseThickness + 2, M3holeDia, M3holeDia, $fn=6);

    // right m3 hold
	translate([-baseWidth / 2, 0, 0]) 
	cylinder(baseThickness + 2, M3holeDia / 2, M3holeDia/2, $fn=30);

    // countersink
	translate([-baseWidth / 2, 0, 2]) 
    rotate([0, 0, 30])
	cylinder(baseThickness + 2, M3holeDia, M3holeDia, $fn=6);
}


rotate([0, 0, 90])
difference(){
	mainShape();
	cutout();
	mountingHoles();
    
}

// show ball?
//translate([0, 0, baseHeight]) 
//    sphere(ballDiameter/2, $fn=50);

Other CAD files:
parts/CAD files/Chassis_Arduino2.scad
parts/CAD files/Pen_Collar2.scad
parts/CAD files/Pen_Holder2.scad

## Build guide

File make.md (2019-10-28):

# Make Your DoodleBot!

You can assemble your DoodleBot in just a few steps.

Thanks to the MakerBox by Ken, where we borrowed the initial design of the chassis from. 

## 1. Collect parts

First, you will need to gather a few parts.

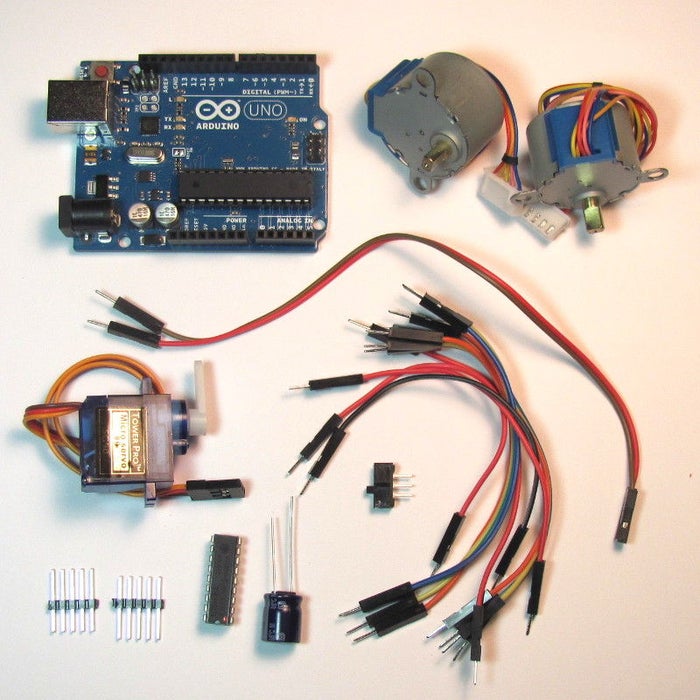
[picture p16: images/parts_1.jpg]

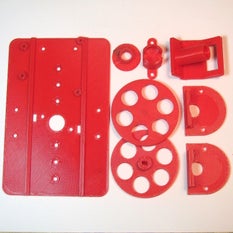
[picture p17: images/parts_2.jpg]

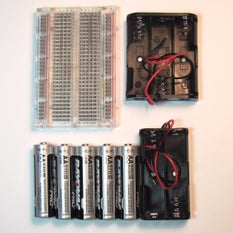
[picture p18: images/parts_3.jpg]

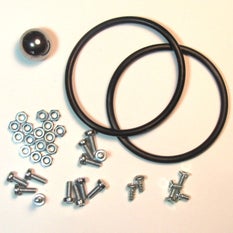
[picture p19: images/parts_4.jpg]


### Electronics:
* 1x Arduino UNO or equivalent- adafruit.com/products/50
(Adafruit is now the US Manufacture for Genuine Arduinos! Get them from the source.)
* 2x Geared 5V Stepper- adafruit.com/products/858
* 1x ULN2803 Darlington Driver - adafruit.com/products/970
* 1x Half-size breadboard- adafruit.com/products/64
* 12x Male-male jumpers- adafruit.com/products/1956
(At least two should be 6", the rest can be 3".)
* 1x Micro servo- adafruit.com/products/169
* 1x Male pin header- digikey.com/short/t93cbd
* 1x 2 x AA Holder- digikey.com/short/tz5bd1
* 1x-3 x AA Holder- digikey.com/short/t5nw1c
* 1x-470 uF 25V capacitor - www.digikey.com/product-detail/en/ECA-1EM471/P5155-ND/245014
* 1x SPDT slide switch - www.digikey.com/product-detail/en/EG1218/EG1903-ND/101726
* 1x USB micro cable http://amzn.com/B00OC6WR22
* 5x AA Batteries

### Hardware:
* 2x 1 7/8" ID x 1/8" O-ring- mcmaster.com/#9452K96
* 1x Caster 5/8" bearing- mcmaster.com/#96455k58/=yskbki
* 10x M3 x 8mm pan head screw- mcmaster.com/#92005a118/=z80pbr
* 4x M3 x 6mm flat head screw- mcmaster.com/#91420a116/=yskru0
* 12x M3 Nut- mcmaster.com/#90591a250/=yskc6u3D
* 2x 1/4" thread forming 4-20 screws http://www.mcmaster.com/#90380A106

### Printed Parts:
* You can find the parts (both in STL and CAD format) here: https://github.com/mitmedialab/doodlebot/blob/master/parts

### Supplies: 
* Phillips screw driver
* Hot glue gun
* Digital multi-meter
* Sharp knife
* Crayola colored markers

## 2. Test Firmware

Before we get too far into construction, lets load the test firmware on to the microcontroller. The test program just draws for boxes so we can check for proper direction and dimension.

1. Download the Arduino software from www.arduino.cc/en/Main/Software
2. Open the Arduino software.
3. Download the attached zip file and unzip it to the Arduino sketchbook location.
* You can find (or change) this location in the Arduino IDE: [File] -> [Preferences]-> "Sketchbook Location".
4. Load the test sketch: [File] -> [Sketchbook] -> [TIRL_Arduino_TEST]
5. Attach your Arduino to your computer with a USB cable.
6. In the Arduino IDE:
  * Set you board type: [Tools] -> [Board] -> Your board type.
  * Set your serial port: [Tools] -> [Port] -> Usually the last one listed.
7. Upload the sketch using the arrow icon.

If you have any problems, refer to www.arduino.cc/en/Guide/Troubleshooting for help.

## 3. Pen Holder and Battery Holders

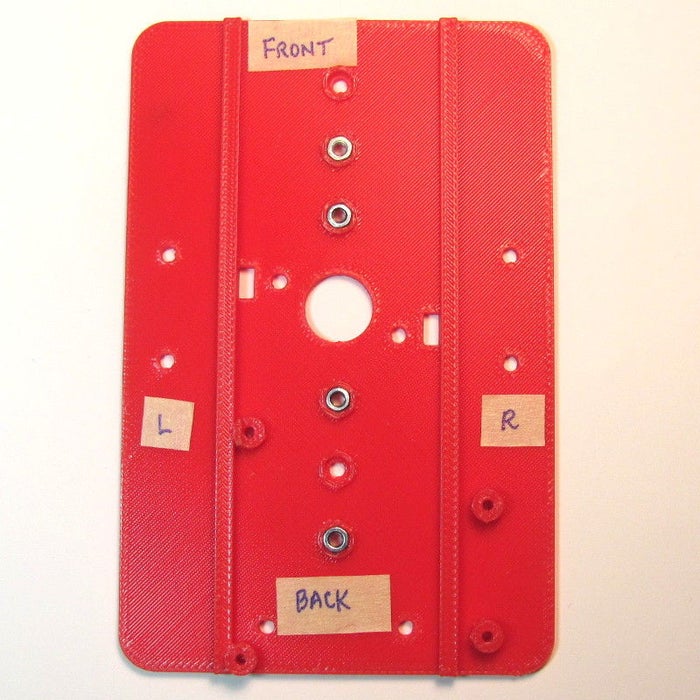
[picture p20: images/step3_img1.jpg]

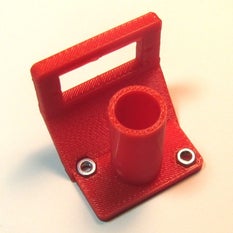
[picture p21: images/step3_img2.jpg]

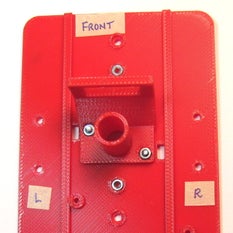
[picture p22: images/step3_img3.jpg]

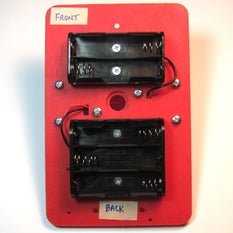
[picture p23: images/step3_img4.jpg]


1. Insert the nuts on the top side of the chassis (Image 1). You may have to press them in.
2. Install the Pen Holder with the Servo Bracket on the top side of the chassis (Image 2 & 3). 
3. Attach the battery holders on the bottom of the chassis using 3Mx6mm flat-head screws (Image 4)
  * You need at least 5xAA to properly power an Arduino via its onboard regulartor. Six would work as well. 
  * You want the weight shifted toward the caster, so put the 3xAA towards the back. 
  * Orient the holders so the leads are closest to the rectangular cable runs. 
4. Thread the battery leads through the rectangular cable runs (Image 4). 
5. Repeat for the other battery holder. 
**Note:** Unless specified, the remainder of the screws are 3Mx8mm pan head screws.

## Step 4. Stepper Brackets

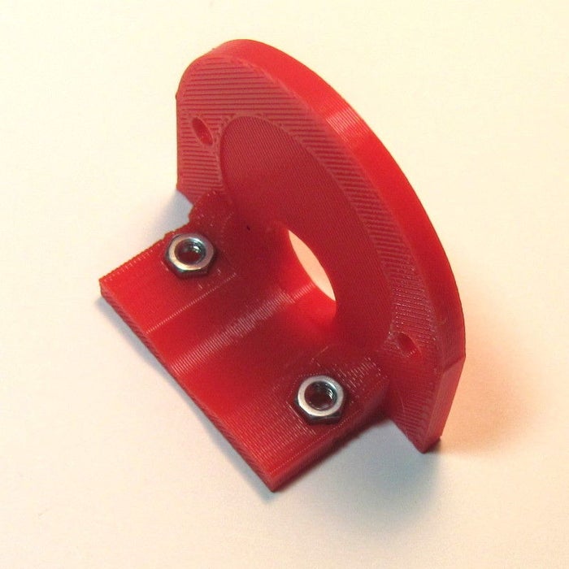
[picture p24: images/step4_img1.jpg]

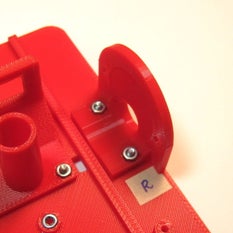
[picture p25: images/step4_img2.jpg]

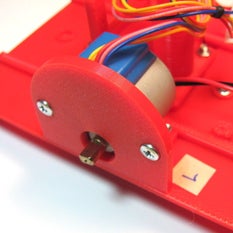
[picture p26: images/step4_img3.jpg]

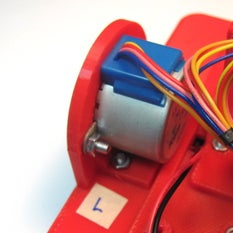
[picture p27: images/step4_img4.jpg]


1. Insert a nut into the stepper bracket and attach them to the top of the chassis with a screw (Image 1).
2. Insert the stepper into the bracket and attach with screws and nuts.
3. Repeat for the other bracket.

## Step 5. Caster

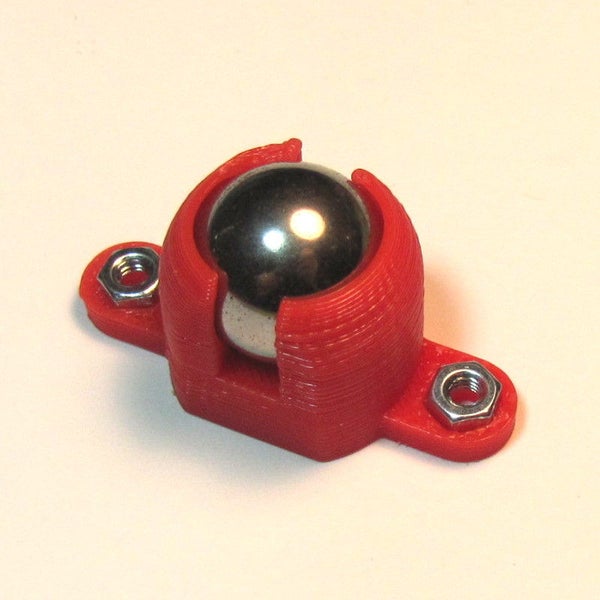
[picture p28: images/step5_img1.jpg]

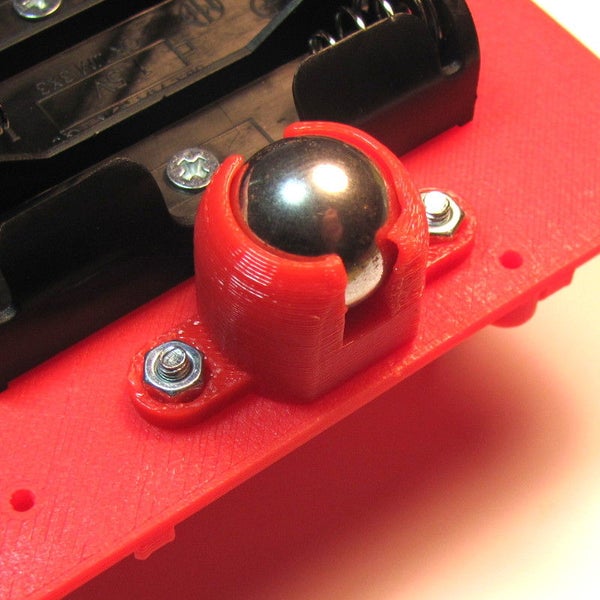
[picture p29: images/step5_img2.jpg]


1. Insert the ball bearing into the caster. 
  * Do not force it in or it will break. Use a hair-drier or hot air gun to soften the material if needed.
2. Attach the caster to the bottom side of the chassis in front of the battery holder.
**Note:** If you need a different diameter, you can edit the openScad file (http://www.thingiverse.com/thing:1052674) to fit what ever you have on hand.

## Step 6. Breadboard and Brains

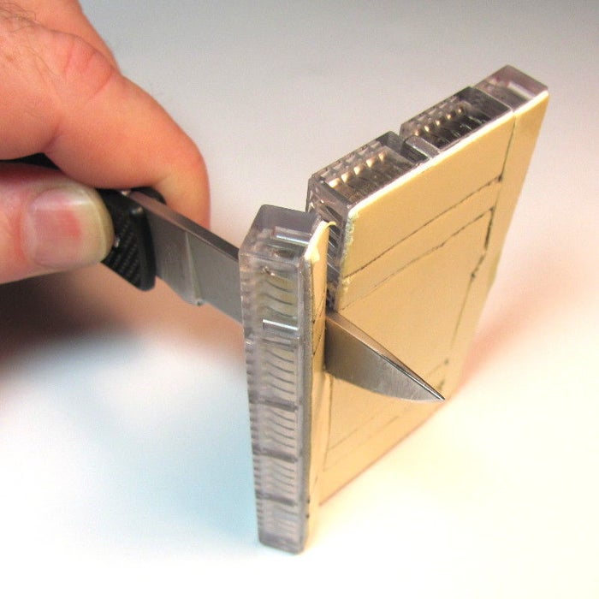
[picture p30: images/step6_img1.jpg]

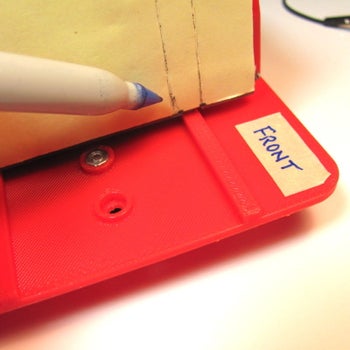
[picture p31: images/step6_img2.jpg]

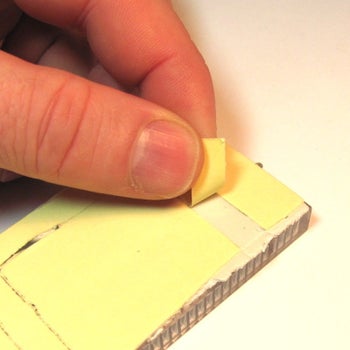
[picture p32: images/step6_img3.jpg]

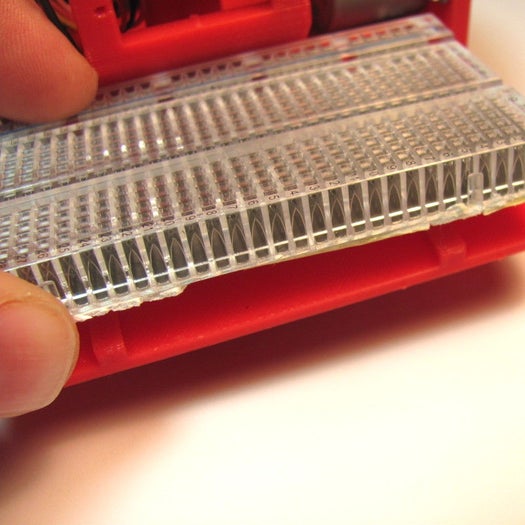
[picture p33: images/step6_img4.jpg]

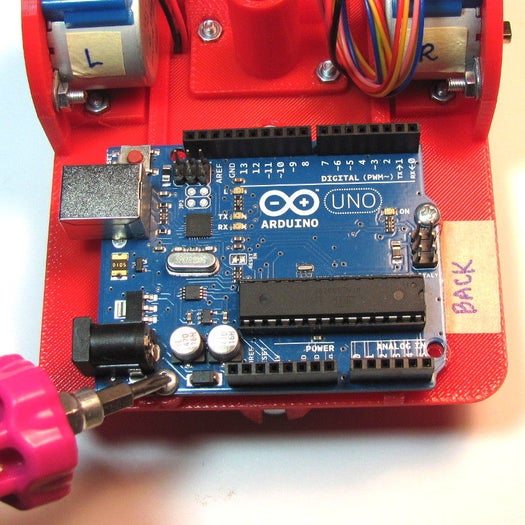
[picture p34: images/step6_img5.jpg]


1. Remove one of the power rails using a sharp knife, cutting through the bottom adhesive (Image 1).
  * One rail has power (red) on outer edge, they other negative (blue). I'm keeping the first attached, and it will match the schematics and photos. If you use the other, just adjust the wires accordingly.
2. Holding the breadboard over the chassis rails, mark where they intersect the edge (Image 2).
3. Using a straight edge (like the removed power rail), mark the lines and cut through the backing (Image 3).
4. Place the breadboard on the chassis with the rails touching the exposed adhesive (Image 4).
5. Attach the Arduino to the other side of the chassis using 4-20 screws (Image 5).

## Step 7. Capacitor and Part Placement

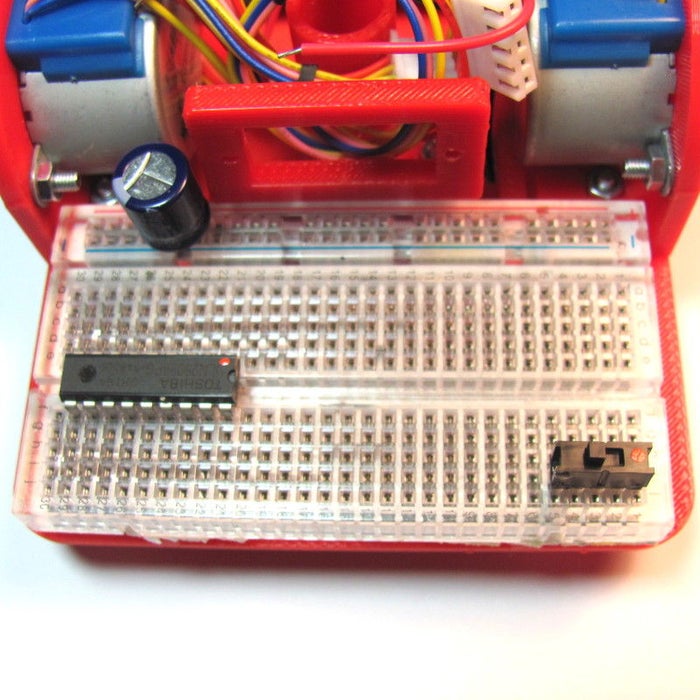
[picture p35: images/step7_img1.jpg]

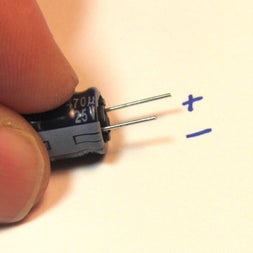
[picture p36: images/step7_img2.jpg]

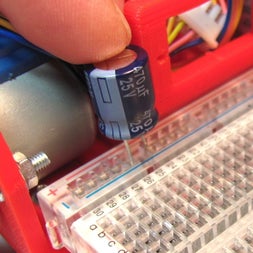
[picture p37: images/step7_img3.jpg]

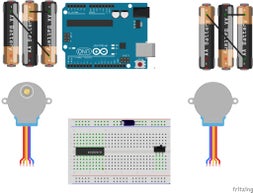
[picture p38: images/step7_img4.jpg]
<br/><br/><br/><br/>

1. Place the darlington driver and power switch on to the bread board (Image 1).
  * I've added orange dots for visibility to mark the following:
    * Pin 1 of the darlington driver
    * The battery pin of the microtroller.The power switch "on" position.
2. Trim the capacitor leads if necessary (longer is negative) (Image 2).
3. Insert the capacitor into the correct rails on the top of the breadboard (Image 3).

## Step 8. Power

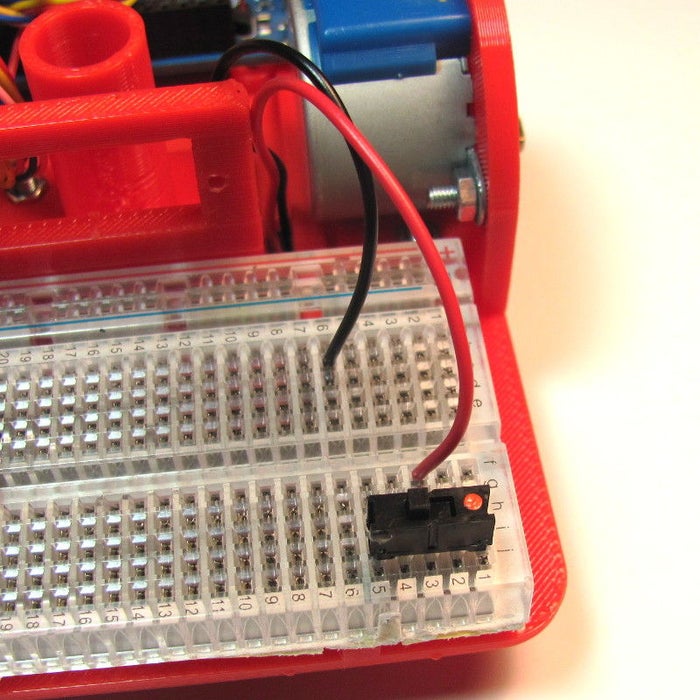
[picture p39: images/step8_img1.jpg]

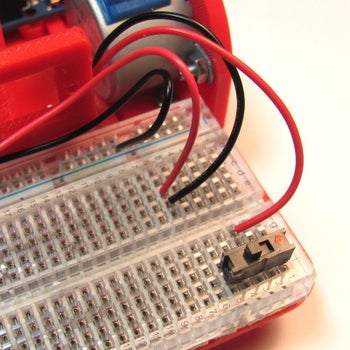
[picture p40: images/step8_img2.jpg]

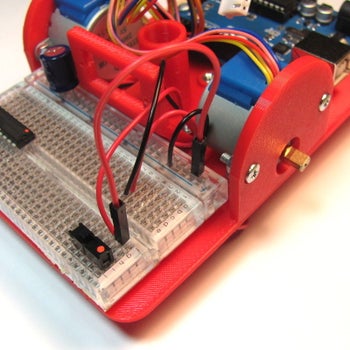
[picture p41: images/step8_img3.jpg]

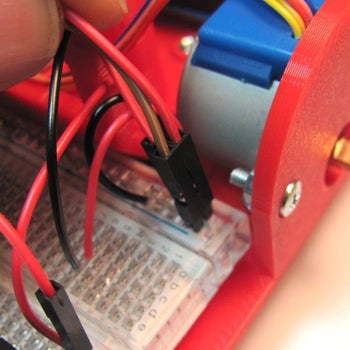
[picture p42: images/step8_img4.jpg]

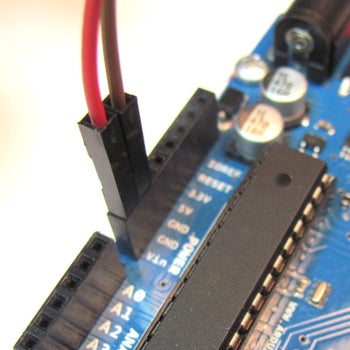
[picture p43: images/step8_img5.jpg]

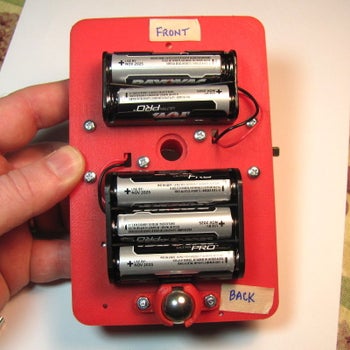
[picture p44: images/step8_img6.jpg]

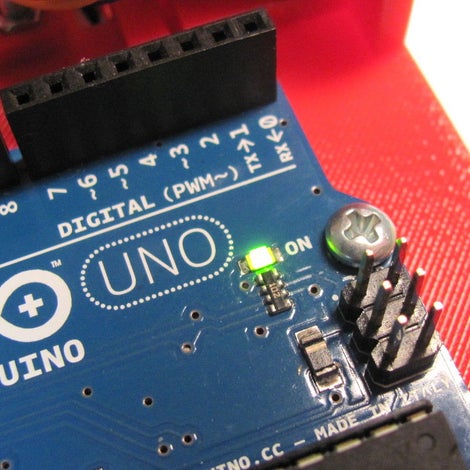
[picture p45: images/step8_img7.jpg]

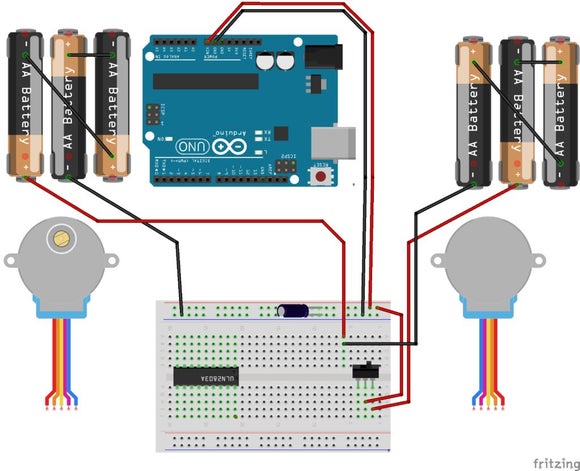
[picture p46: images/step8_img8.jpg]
<br/><br/><br/><br/>

1. With the right-hand battery leads:Connect the red line to the first pin of the power switch (Image 1).
2. Connect the black lead to an empty row between the microcontroller and the darlington chip (Image 1).
3. With the left-hand battery leads:Connect the red line to the same row as the black lead of the other battery (Image 2).
4. Connect the black line to the negative rail of the breadboard (Image 2).
5. Connect power to the microcontroller:
  1. Red jumper from positive rail to the battery pin (orange dot, Image 3).
  2. Black jumper from the negative rail to the pin marked "G" (Image 4).
6. Install batteries and switch the power on (Image 5).
7. You should see the green and red lights of the controller come on (Image 6).

**Troubleshooting:**
  * If the microcontroller lights do not come on, **immediately** turn the power off and troubleshoot:
    * Batteries installed in the correct orientation?
    * Double check battery leads positioning.
    * Double check switch leads positioning.
    * Use a multi-meter to check voltages of batteries.
    * Use multi-meter to check power rail voltages.
    
## Step 9. Stepper Power





Now that you've got power to the microcontroller, let's finish wiring power to the steppers:

1. Connect a black jumper from the upper left darlington pin to the negative side of the power rail (Image 1).
2. Connect a red jumper from the lower left darlington pin to the positive side of the power rail (Image
3. Connect a red jumper from the lower left darlington pin to one row right of the darlington (Image 2).
4. Insert pin headers for the stepper's white JST connectors (Image 2).

## Step 10. Stepper Control Signals

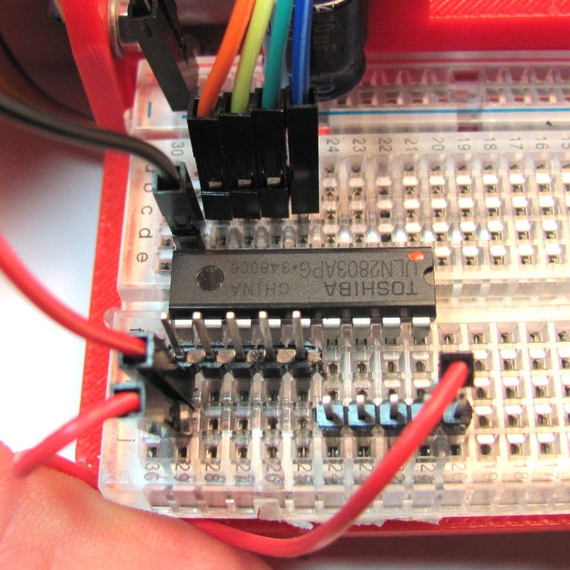
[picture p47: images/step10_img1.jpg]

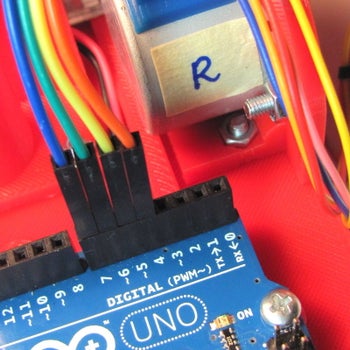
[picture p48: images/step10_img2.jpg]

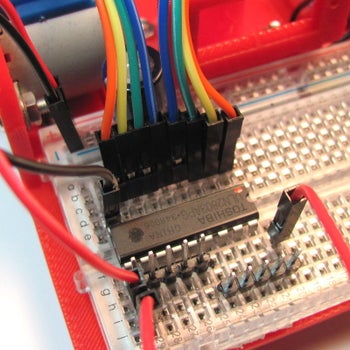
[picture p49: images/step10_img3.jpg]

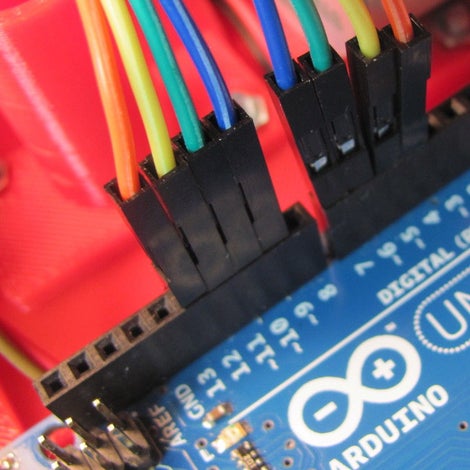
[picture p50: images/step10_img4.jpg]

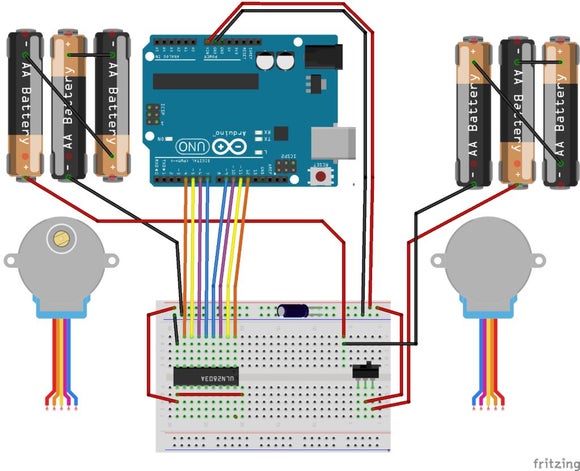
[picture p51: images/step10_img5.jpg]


The microcontroller provides 5 volt signals to the darlington array which in turn, provides VCC to the stepper coils:

1. Start with pin next to the ground pin on the darlington driver, and install orange, yellow, green, and blue wires in that order (Image 1).
2. Attach the jumpers to the following arduino pins (Image 2):
  * 1. orange - Digital pin 4
  * 2. yellow - Digital pin 5
  * 3. green - Digital pin 6
  * 4. blue - Digital pin 7
3. Back at the darlington, continue jumper for the other stepper in the reverse of the others:
  * blue, green, yellow, and orange (Image 3).
4. Attach the jumpers to the following arduino pins (Image 4):
  * 1. blue - Digital pin 9 (pin 8 used latter for the servo).
  * 2. green - Digital pin 10
  * 3. yellow - Digital pin 11
  * 4. orange - Digital pin 12
  
  ## Step 11: Stepper Coil Connections
  
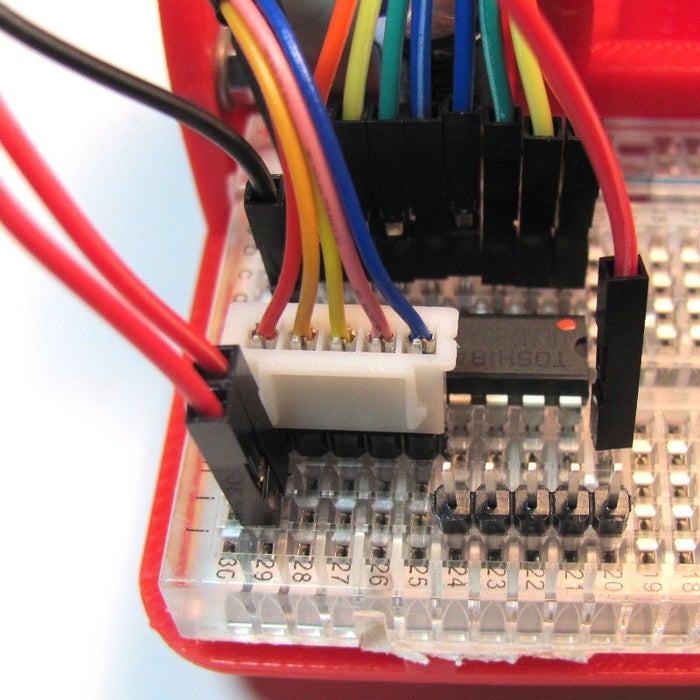
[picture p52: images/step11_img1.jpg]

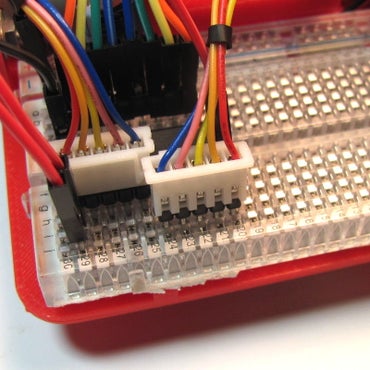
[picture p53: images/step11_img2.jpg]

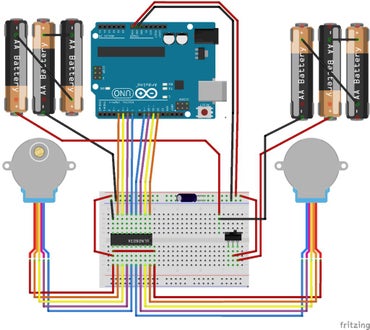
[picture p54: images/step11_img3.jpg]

  
 The stepper's white JST connectors attach to the pin header. The red lead is power, and should match the red power jumpers we installed earlier (Image 1).

All colors should match the microcontroller jumpers on the opposite side of the darlington, with the exception of green, which matches the pink wire of the stepper (Image 2).

## Step 12: Servo

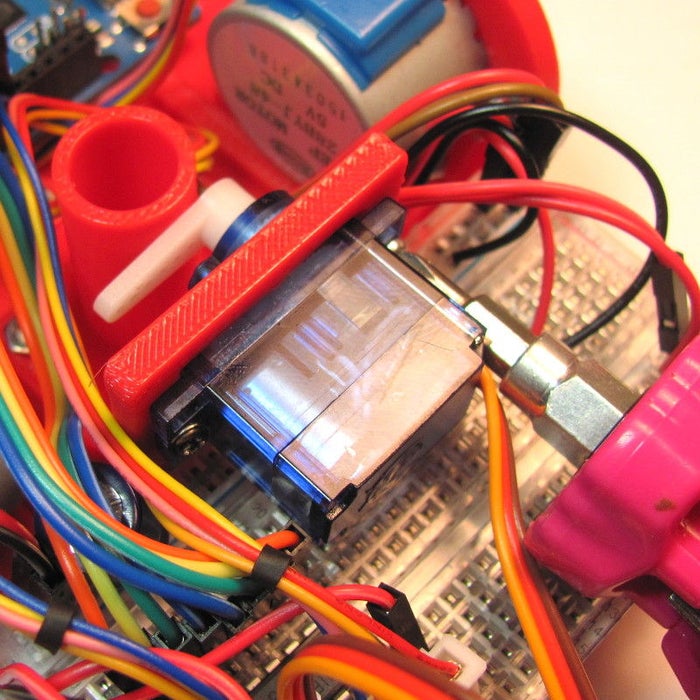
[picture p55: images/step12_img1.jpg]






1. Install the servo horn with the servo rotated clockwise to the stop and the horn horizontal (Image 1).
2. Attach the servo to the holder, and the horn pointed to the right stepper side (Image 1).
3. Attach brown (ground), red (5V power), and white (signal) jumpers into the servo connector, matching the servo wire colors (Image 2).
4. Attach the power and ground jumpers to the ground and 5V header on the Arduino (Image 3).
5. Connect the white signal wire to the Arduino's Digital Pin 8 (Image 4).

## Step 13: Wheels




1. Place the rubber o-ring around the edge of the wheel (Image 1).
2. If the fit of the hub on the axle is loose, you can use a 3M screw to hold it in place (Image 2).
  * Do not tighten it too much or you will strip the plastic.
  
## Step 14: Testing

Hopefully you already uploaded the firmware in Step 2. If not, do it now.

The test firmware just draws a square repeatedly so we can check direction and accuracy.

1. Place your robot on a smooth, flat, open surface.
2. Turn the power on.
3. Watch your robot draw squares.
If you are not seeing lights on the microcontroller, go back and troublshoot power as in Step 8.

If your robot is not moving, double check the power connections to the darlington driver in Step 9.

If your robot is moving erratically, double check the pin connections for the microcontroller and darlington driver in Step 10.

## Step 15: Calibration 






If your robot is moving in an approximate square, it is time to put some paper down and put a pen in it.

Measure your wheel diameter (Image 1) and wheel base (Image 2) in millimeters.

Your calibration settings in the code are:
```
float wheel_dia=63;     // mm (increase = spiral out)
float wheel_base=109;   // mm (increase = spiral in)
int steps_rev=128;      // 128 for 16x gearbox, 512 for 64x gearbox
```
I started with a measured wheel diameter of 65 mm and you can see the boxes rotating outward or clockwise each step (Image 3).

I eventually arrived at a value of 63mm (Image 4). You can see that there is still some inherent error due to gear lash and such. Close enough to do something interesting!

## Step 16: Raising and Lowering the Pen




We've added a servo, but haven't done anything with it. It allows you to raise and lower the pen so the robot can move without drawing.

1. Place the pen collar on the pen (Image 1).
  * If it is loose, tape it in place.
2. Check that it will touch the paper when the servo arm is lowered.
3. Check that it will not touch the paper when raised.

The servo angles can be adjusted either by removing the horn and re-positioning it, or through the software:
```
int PEN_DOWN = 20; // angle of servo when pen is down
int PEN_UP = 80;   // angle of servo when pen is up
```

The pen commands are:
```
penup(); 
pendown();
```
If you want to use different pen sizes, you will have to modify the pen holder (www.thingiverse.com/thing:1052725) and pen collar (www.thingiverse.com/thing:1053273) with the correct diameter.

## Step 17: Have Fun!

Now it is time to explore. If you look at the test sketch, you will see I have provided you some standard "Turtle" commands:

```
forward(distance);   // millimeters
backward(distance);
left(angle);         // degrees
right(angle);
penup();
pendown();
done();              // release stepper to save battery
```

Using these commands, you should be able to do just about anything, from drawing snow flakes or writing your name. If you need some help getting started, click on the videos below!

The Solution using Standard Markdown ( not iFrame! )
Using an iframe is not the "obvious" solution... especially if the Markdown parser (or publishing platform) you are using does not support inlining content from a different website ... Instead you can "fake it" by including a valid linked-image in your Markdown file, using this format:

Robots ROCK (https://www.youtube.com/embed/unAPCqIWjis "Robots ROCK")

Arduino Drawing robot doing random patterns (https://www.youtube.com/embed/rsgMDhodtPg "Arduino Drawing robot doing random patterns")

## Step 18: Other Platforms




*Could this robot be done with a -Insert your favorite board here-?*

Yes! This platform is very flexible. You would mainly just need to modify the chassis.

Above, you can see the robot made with a Raspberry Pi (Image 1) and an Adafruit Trinket (www.instructables.com/id/Low-Cost-Arduino-Compatible-Drawing-Robot/) (Image 2).

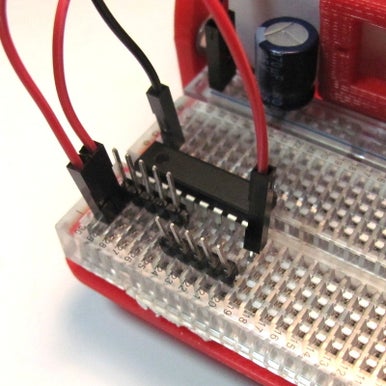
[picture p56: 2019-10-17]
images/step9_img2.jpg

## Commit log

2019-10-15 adding parts and images
    [Caster2.scad, Caster2.stl, Chassis_Arduino2.scad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]
2019-10-27 programming calibration instructions
2021-01-25 add calibration details
